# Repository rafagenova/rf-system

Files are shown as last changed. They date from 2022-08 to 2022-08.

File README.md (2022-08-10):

# radio frequency system for sending and reception of data

## 1. NRF905 notes

### &bull; nrf905 timing to obey info

| nrf905 timing | max | 
| --- | --- |
| power down mode to standby mode | 3 ms |
| standby mode to TX shock burst mode | 650 us |
| standby mode to RX shock burst mode | 650 us |
| RX shock burst mode to TX shock burst mode | 550 us |
| TX shock burst mode to RX shock burst mode | 550 us |

### &bull; nrf905 modulation
the modulation of nRF905 is Gaussian Frequency Shift Keying (GFSK) with a datarate of 100kbps.
</br> the data is internally Manchester encoded (TX) and Manchester decoded (RX).

### &bull; nrf905 output frequency

Output Frequency
The operating RF-frequency of nRF905 is set in the configuration register by CH_NO and HFREQ_PLL.

| operating frequency|
| ----------- | 
| <i> f = (422.4 + (CH_NO)/10)&bull; (1 + HFREQ_PLL) MHz </i>| 

<i> obs1: CH_NO varies from '000000000' to '1111111111' </i>

<i> obs2: HFREQ_PLL varies from '0' to '1' </i>

| Operating frequency | HFREQ_PLL | CH_NO | 
| --- | --- | --- |
| 430.0 MHz |  [0] | [001001100]  |
| 433.1 MHz |  [0] | [001101011]  |
| 433.2 MHz |  [0] | [001101100]  |
| 434.7 MHz |  [0] | [001111011]  |
| 862.0 MHz |  [1] | [001010110]  |
| 868.2 MHz |  [1] | [001110101]  |
| 868.4 MHz |  [1] | [001110110]  |
| 869.8 MHz |  [1] | [001111101]  |
| 902.2 MHz |  [1] | [100011111]  |
| 902.4 MHz |  [1] | [100100000]  |
| 927.8 MHz |  [1] | [110011111]  |

### &bull; nrf905 antenna ports impedance

| optimum differential load impedance at the antenna ports| frequency | 
| --- | --- |
| 225&Omega; + j210 |  900MHz | 
| 300&Omega; + j100 |  430MHz | 

<i> obs: a low load impedance (for instance 50&Omega;) can be obtained by fitting a simple matching network or a RF transformer (balun) </i>

### &bull; PCB layout and decoupling guidelines

<i> 

1. A PCB with a minimum of two layers including a ground plane is recommended for optimum performance.

2. The nRF905 DC supply voltage should be decoupled as close as possible to the VDD pins with high performance RF capacitors.

3. It is preferable to mount a large surface mount capacitor (e.g. 4.7uF tantalum) in parallel with the smaller value capacitors.

4. The nRF905 supply voltage should be filtered and routed separately from the supply voltages of any digital circuitry.

5. Long power supply lines on the PCB should be avoided.

6. All device grounds, VDD connections and VDD bypass capacitors must be connected as close as possible to the nRF905 IC.

7. For a PCB with a topside RF ground plane, the VSS pins should be connected directly to the ground plane.

8. For a PCB with a bottom ground plane, the best technique is to place via holes as close as possible to the VSS pins (a minimum of one via hole should be used for each VSS pin).

9. Full swing digital data or control signals should not be routed close to the crystal or the power supply lines.

10. A fully qualified RF-layout for the nRF905 and its surrounding components, including antennas and matching networks, can be downloaded from <b> www.nordicsemi.no. </b>

</i>

| nrf905 features | description | 
| --- | --- |
| &bull; Carrier detect | When the nRF905 is in ShockBurst TM RX, the Carrier Detect (CD) pin is set high if a RF carrier is present at the channel the device is programmed to. </br > </br > This feature is very effective to avoid collision of packages from different transmitters operating at the same frequency. </br > </br > Whenever a device is ready to transmit it could first be set into receive mode and sense whether or not the wanted channel is available for outgoing data. |
| &bull; Address match | When the nRF905 is in ShockBurst TM RX mode, the Address Match (AM) pin is set high as soon as an incoming package with an address that is identical with the device’s own identity is received. </br > </br > If Address Match (AM) is high then the MCU can make a decision to wait and see if Data Ready (DR) will be set high indicating a valid data package has been received or ignore that a possible package is being received and switch modes.|
|  &bull; Data ready | In ShockBurst TM TX Auto Retransmit the Data Ready (DR) signal is set high at the beginning of the pre-amble and is set low at the end of the preamble. The Data Ready (DR) signal therefore pulses at the beginning of each transmitted data packet.  </br > </br > In ShockBurst TM RX, the signal is set high when nRF905 has received a valid package, i.e. a valid address, package length and correct CRC. The MCU can then retrieve the payload via the SPI interface. The Data Ready (DR) pin is reset to low once the data has been clocked out of the data buffer or the device is switched to transmit mode.|
|  &bull; Auto retransmit | One way to increase system reliability in a noisy environment or in a system without collision control is to transmit a package several times. </br > </br > By setting the AUTO_RETRAN bit to “1” in the configuration register, the circuit keeps sending the same data package as long as TRX_CE and TX_EN is high.|

### &bull; nrf905 schematic example

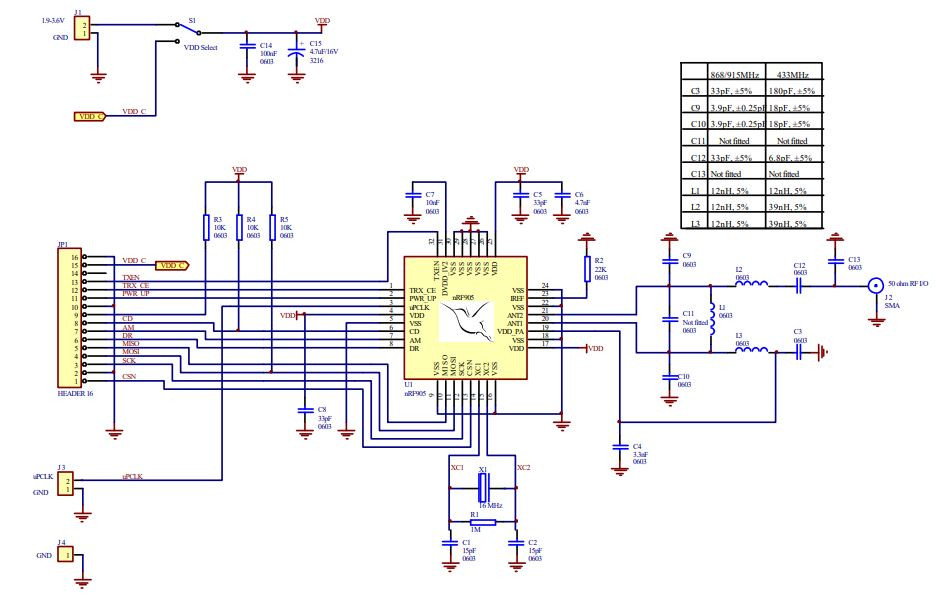
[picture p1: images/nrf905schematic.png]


## 2. Components & schematics

### &bull; voltage regulator (3.7v battery to 3.3v system)

| 3.3V LDO | packacge | comments |
| --- | --- |  --- |
| MCP1700T-3302E/TT |  SOT-23-3 |46 in stock at JLCPCB @ 30/05 <br /> Max current of 250 mA <br /> Max dropout voltage of 350 mV |

### &bull; power input schematic

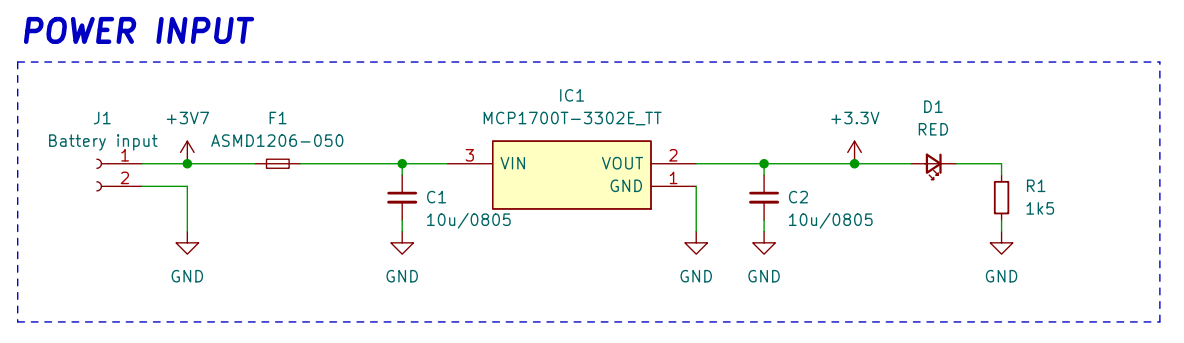
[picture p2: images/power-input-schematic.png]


### &bull; transceiver schematic

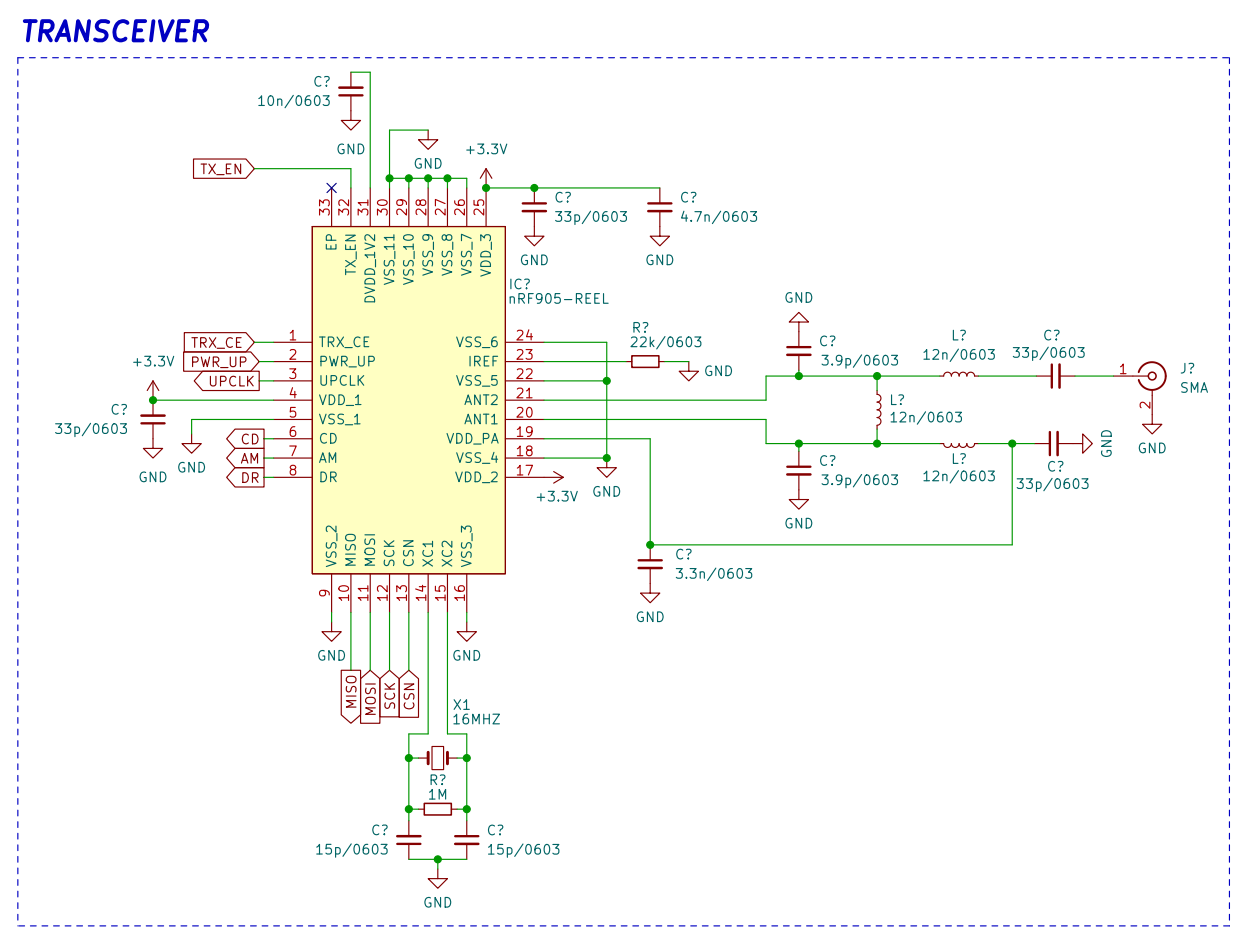
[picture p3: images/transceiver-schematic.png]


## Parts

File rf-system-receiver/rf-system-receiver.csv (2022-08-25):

Comment | Designator | Footprint | LCSC Part #
33p/0603 Unpolarized capacitor, small symbol | C1,C6,C12,C13 | C_0603_1608Metric
22u/1206 Unpolarized capacitor, small symbol | C2,C8 | C_1206_3216Metric
10n/0603 Unpolarized capacitor, small symbol | C3 | C_0603_1608Metric
10p/0402 Unpolarized capacitor, small symbol | C4,C5,C19,C20 | C_0402_1005Metric
3.3n/0603 Unpolarized capacitor, small symbol | C7 | C_0603_1608Metric
4.7n/0603 Unpolarized capacitor, small symbol | C9 | C_0603_1608Metric
3.9p/0603 Unpolarized capacitor, small symbol | C10,C11 | C_0603_1608Metric
10u/0805 Unpolarized capacitor, small symbol | C14,C21 | C_0805_2012Metric
100n/0402 Unpolarized capacitor, small symbol | C15,C16,C17,C18,C23 | C_0402_1005Metric
10n/0402 Unpolarized capacitor, small symbol | C22 | C_0402_1005Metric
RED Light emitting diode, small symbol | D1,D2 | LED_0603_1608Metric
ASMD1206-050 Fuse, small symbol | F1 | Fuse_1206_3216Metric
100@100MHz/0603 Ferrite bead, small symbol | FB1 | L_0603_1608Metric
Fiducial Fiducial Marker | FID1,FID2,FID3,FID4 | Fiducial_1mm_Mask2mm
MountingHole Mounting Hole without connection | H1,H3 | MountingHole_3.2mm_M3
nRF905 HF-Transceiver 1.9-3.6V 433/868/ 915MHz TRNSCVR | IC1 | nrf905
USB_B_Micro USB Connectors 5P MICRO USB TYPE B RECEPTACLE W/ PEGS | J1 | 101181930001LF
CONREVSMA001-G RF Connectors / Coaxial Connectors RP-SMA Female PCB Mount - Gold | J2 | CONREVSMA001G
SWD Generic connector, double row, 02x05, odd/even pin numbering scheme (row 1 odd numbers, row 2 even numbers), script generated (kicad-library-utils/schlib/autogen/connector/) | J3 | PinHeader_2x05_P2.54mm_Vertical_SMD
12n/0603 Inductor, small symbol | L1,L2,L3 | L_0603_1608Metric
MMBT9013 NPN transistor, base/collector/emitter | Q1 | SOT-23
1M/0402 Resistor, small symbol | R1 | R_0402_1005Metric
22k/0603 Resistor, small symbol | R2 | R_0603_1608Metric
1k5/0603 Resistor, small symbol | R3,R7 | R_0603_1608Metric
10k/0603 Resistor, small symbol | R4,R6,R9 | R_0603_1608Metric
47R/0402 Resistor, small symbol | R5 | R_0402_1005Metric
100R/0603 Resistor, small symbol | R8,R11 | R_0603_1608Metric
36k/0603 Resistor, small symbol | R10 | R_0603_1608Metric
SW_Push Push button switch, generic, two pins | SW1 | SW_PUSH_6mm
STM32F103C8Tx ARM Cortex-M3 MCU, 64KB flash, 20KB RAM, 72MHz, 2-3.6V, 37 GPIO, LQFP-48 | U1 | LQFP-48_7x7mm_P0.5mm
AMS1117-3.3 1A Low Dropout regulator, positive, 3.3V fixed output, SOT-223 | U2 | SOT-223-3_TabPin2
16MHZ Four pin crystal, GND on pins 2 and 4, small symbol | X1,X2 | Crystal_SMD_3225-4Pin_3.2x2.5mm

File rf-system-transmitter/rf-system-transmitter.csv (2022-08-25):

Comment | Designator | Footprint | LCSC Part #
33p/0603 Unpolarized capacitor, small symbol | C1,C6,C13 | C_0603_1608Metric
10u/0805 Unpolarized capacitor, small symbol | C2,C8,C14,C21 | C_0805_2012Metric
10n/0603 Unpolarized capacitor, small symbol | C3 | C_0603_1608Metric
10p/0402 Unpolarized capacitor, small symbol | C4,C5,C19,C20 | C_0402_1005Metric
3.3n/0603 Unpolarized capacitor, small symbol | C7 | C_0603_1608Metric
4.7n/0603 Unpolarized capacitor, small symbol | C9 | C_0603_1608Metric
3.9p/0603 Unpolarized capacitor, small symbol | C10,C11 | C_0603_1608Metric
2.2p/0603 Unpolarized capacitor, small symbol | C12 | C_0603_1608Metric
100n/0402 Unpolarized capacitor, small symbol | C15,C16,C17,C18,C23 | C_0402_1005Metric
10n/0402 Unpolarized capacitor, small symbol | C22 | C_0402_1005Metric
RED Light emitting diode, small symbol | D1,D2 | LED_0603_1608Metric
ASMD1206-050 Fuse, small symbol | F1 | Fuse_1206_3216Metric
100@100MHz/0603 Ferrite bead, small symbol | FB1 | L_0603_1608Metric
Fiducial Fiducial Marker | FID1,FID2,FID3,FID4 | Fiducial_1mm_Mask2mm
MountingHole Mounting Hole without connection | H1,H4 | MountingHole_3.2mm_M3
nRF905 HF-Transceiver 1.9-3.6V 433/868/ 915MHz TRNSCVR | IC1 | nrf905
MCP1700T-3302E_TT LDO voltage regulator 250mA Isupply 1uA | IC2 | MCP1700T-3302E_TT
Battery input Generic connector, single row, 01x02, script generated (kicad-library-utils/schlib/autogen/connector/) | J1 | JST_PH_B2B-PH-K_1x02_P2.00mm_Vertical
CONREVSMA001-G RF Connectors / Coaxial Connectors RP-SMA Female PCB Mount - Gold | J2 | CONREVSMA001G
SWD Generic connector, double row, 02x05, odd/even pin numbering scheme (row 1 odd numbers, row 2 even numbers), script generated (kicad-library-utils/schlib/autogen/connector/) | J3 | PinHeader_2x05_P2.54mm_Vertical_SMD
12n/0603 Inductor, small symbol | L1,L2,L3 | L_0603_1608Metric
1M/0402 Resistor, small symbol | R1 | R_0402_1005Metric
22k/0603 Resistor, small symbol | R2 | R_0603_1608Metric
1k5/0603 Resistor, small symbol | R3,R7 | R_0603_1608Metric
10k/0603 Resistor, small symbol | R4,R6 | R_0603_1608Metric
47R/0402 Resistor, small symbol | R5 | R_0402_1005Metric
SW_Push Push button switch, generic, two pins | SW1 | SW_PUSH_6mm
STM32F103C8Tx ARM Cortex-M3 MCU, 64KB flash, 20KB RAM, 72MHz, 2-3.6V, 37 GPIO, LQFP-48 | U1 | LQFP-48_7x7mm_P0.5mm
16MHZ Four pin crystal, GND on pins 2 and 4, small symbol | X1,X2 | Crystal_SMD_3225-4Pin_3.2x2.5mm

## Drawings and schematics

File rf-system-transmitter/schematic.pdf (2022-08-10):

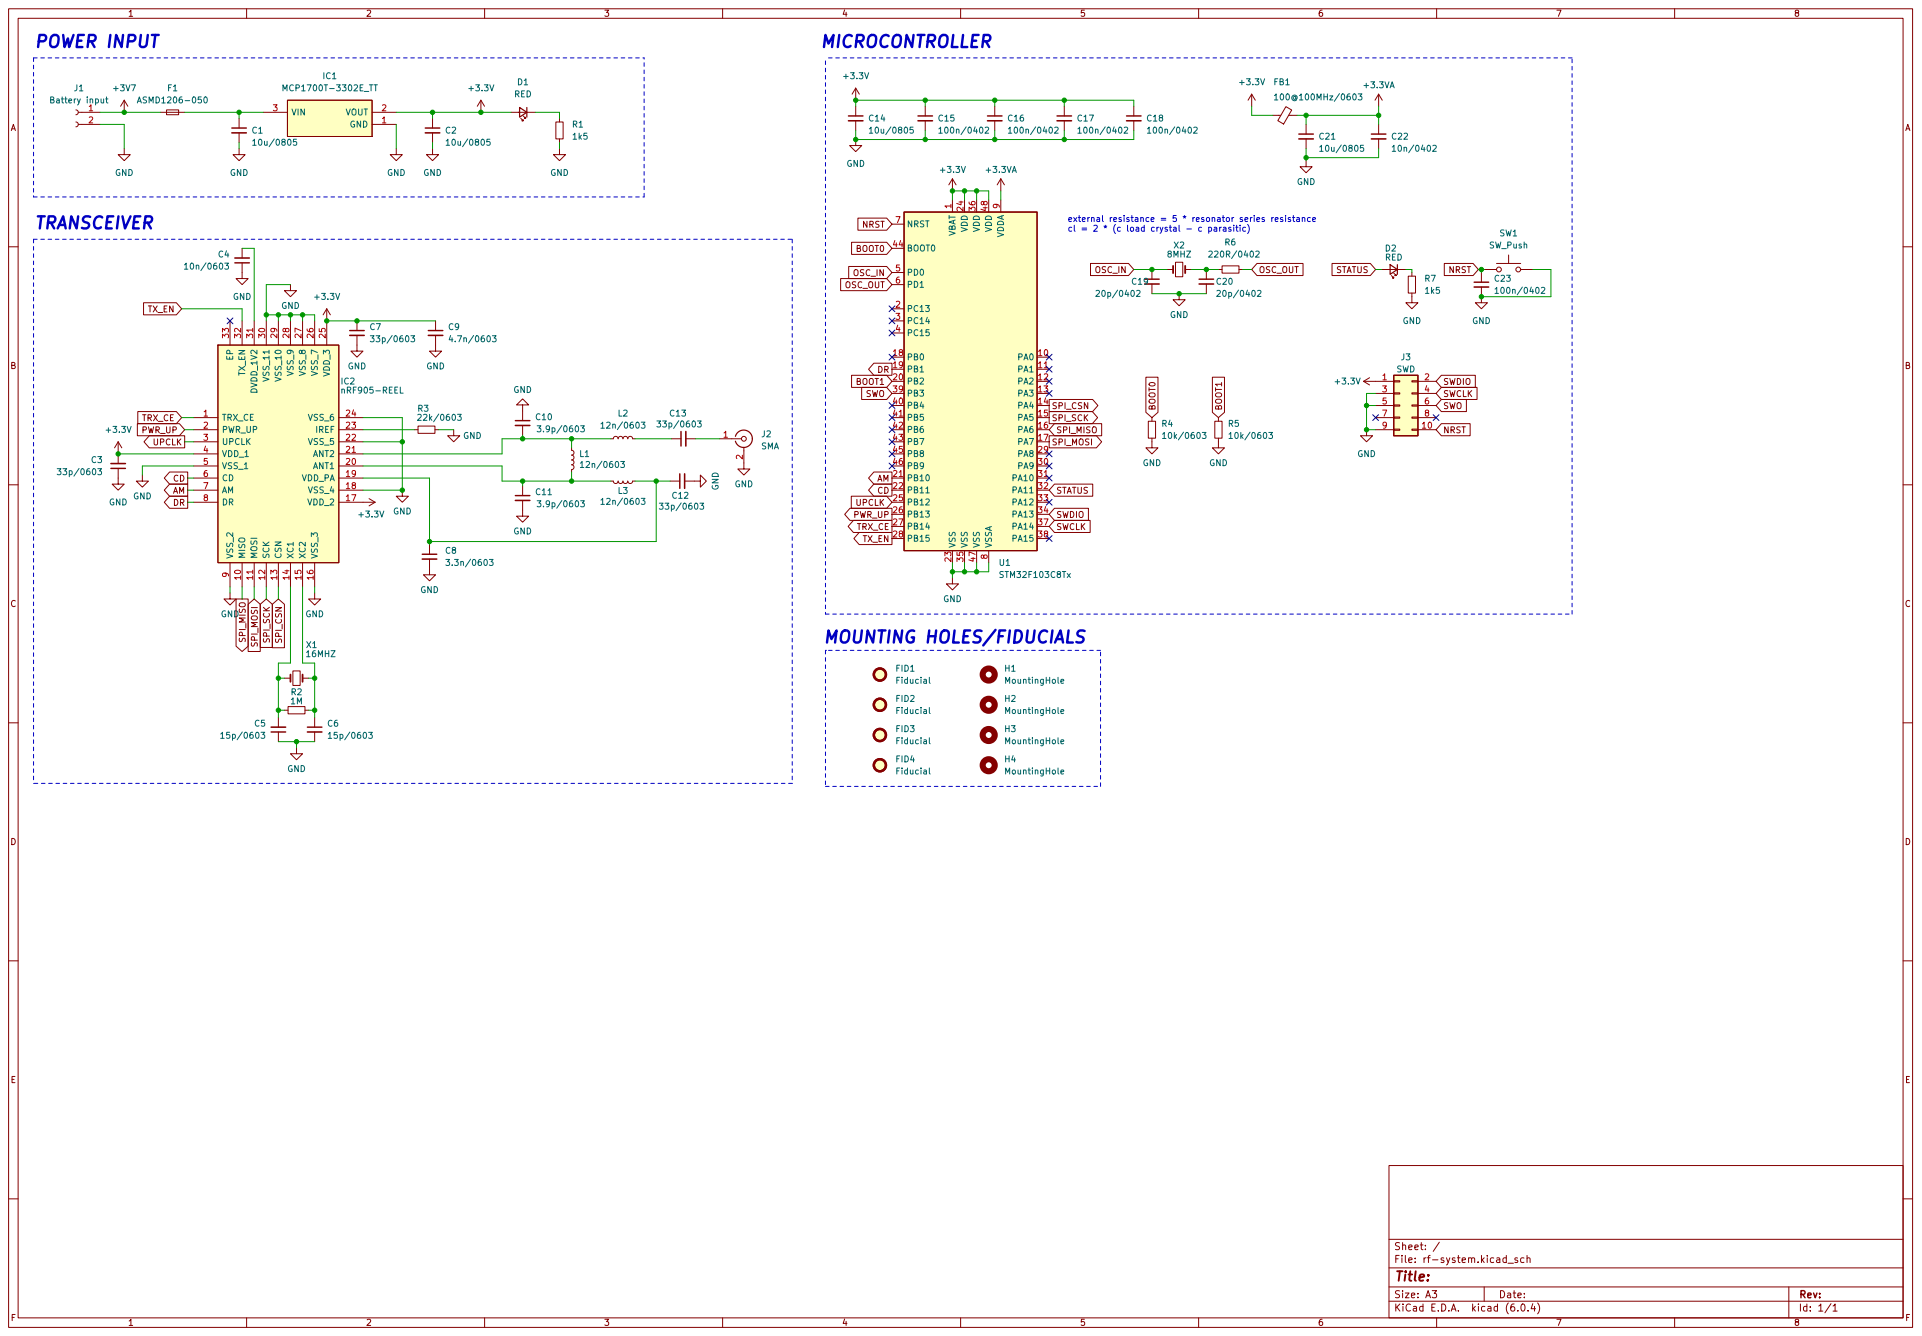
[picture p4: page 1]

1 PA0 10 PA1 11 PA2 12 PA3 13 PA4 14 PA5 15 PA6 16 PA7 17 PB0 18 PB1 19 PC13 2 PB2 20 PB10 21 PB11 22 VSS 23 VDD 24 PB12 25 PB13 26 PB14 27 PB15 28 PA8 29 PC14 3 PA9 30 PA10 31 PA11 32 PA12 33 PA13 34 VSS 35 VDD 36 PA14 37 PA15 38 PB3 39 PC15 4 PB4 40 PB5 41 PB6 42 PB7 43 BOOT0 44 PB8 45 PB9 46 VSS 47 VDD 48 PD0 5 PD1 6 NRST 7 VSSA

cl = 2 * (c load crystal - c parasitic)

SWCLK NRST MOUNTING HOLES/FIDUCIALS
SPI_CSN OSC_OUT SWO

File: rf-system.kicad_sch Sheet: /

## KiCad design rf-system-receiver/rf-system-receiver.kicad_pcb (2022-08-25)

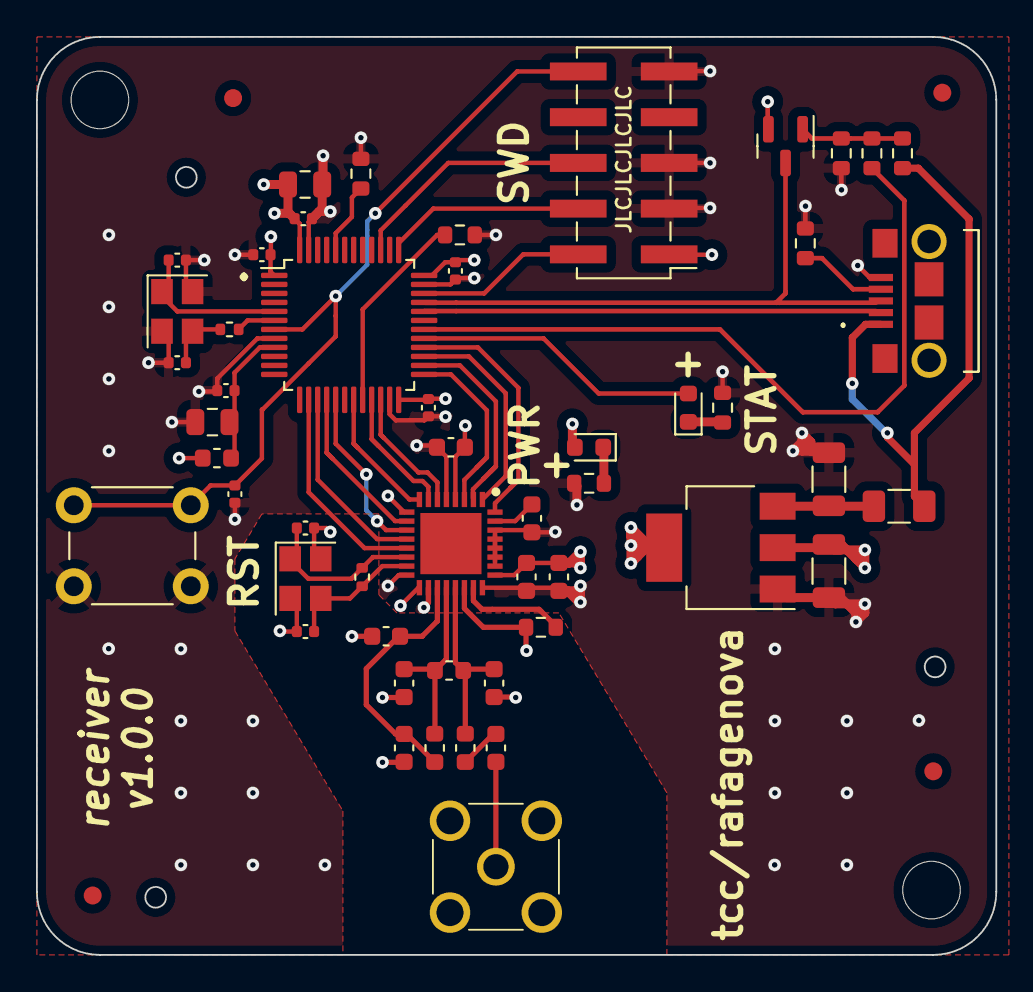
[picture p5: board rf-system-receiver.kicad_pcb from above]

Board: 4 copper layers, 53.3 x 51.0 mm, 57 parts (0 on the bottom side), 42 nets.

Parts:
C1, C6, C12, C13: 33p/0603; C_0603_1608Metric
C2, C8: 22u/1206; C_1206_3216Metric
C3: 10n/0603; C_0603_1608Metric
C4, C5, C19, C20: 10p/0402; C_0402_1005Metric
C7: 3.3n/0603; C_0603_1608Metric
C9: 4.7n/0603; C_0603_1608Metric
C10, C11: 3.9p/0603; C_0603_1608Metric
C14, C21: 10u/0805; C_0805_2012Metric
C15, C16, C17, C18, C23: 100n/0402; C_0402_1005Metric
C22: 10n/0402; C_0402_1005Metric
D1, D2: RED; LED_0603_1608Metric
F1: ASMD1206-050; Fuse_1206_3216Metric
FB1: 100@100MHz/0603; L_0603_1608Metric
FID1, FID2, FID3, FID4: Fiducial; Fiducial_1mm_Mask2mm
H1, H3: MountingHole; MountingHole_3.2mm_M3
IC1: nRF905; nrf905
J1: USB_B_Micro; 101181930001LF
J2: CONREVSMA001-G; CONREVSMA001G
J3: SWD; PinHeader_2x05_P2.54mm_Vertical_SMD
L1, L2, L3: 12n/0603; L_0603_1608Metric
Q1: MMBT9013; SOT-23
R1: 1M/0402; R_0402_1005Metric
R2: 22k/0603; R_0603_1608Metric
R3, R7: 1k5/0603; R_0603_1608Metric
R4, R6, R9: 10k/0603; R_0603_1608Metric
R5: 47R/0402; R_0402_1005Metric
R8, R11: 100R/0603; R_0603_1608Metric
R10: 36k/0603; R_0603_1608Metric
SW1: SW_Push; SW_PUSH_6mm
U1: STM32F103C8Tx; LQFP-48_7x7mm_P0.5mm
U2: AMS1117-3.3; SOT-223-3_TabPin2
X1, X2: 16MHZ; Crystal_SMD_3225-4Pin_3.2x2.5mm

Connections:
+3.3VA: C21.1, C22.1, FB1.2, U1.9 (VDDA)
+3V3: C1.2, C6.1, C8.1, C9.1, C14.1, C15.1, C16.1, C17.1, C18.1, D1.2 (A), FB1.1, IC1.4 (VDD_1), IC1.17 (VDD_2), IC1.25 (VDD_3), J3.1, Q1.2 (C), U1.1 (VBAT), U1.24 (VDD), U1.36 (VDD), U1.48 (VDD), U2.2 (VO)
+5V: F1.1, J1.1 (VBUS), R9.1
AM: IC1.7 (AM), U1.21 (PB10)
BOOT0: R4.1, U1.44 (BOOT0)
BOOT1: R6.1, U1.20 (PB2)
CD: IC1.6 (CD), U1.22 (PB11)
DR: IC1.8 (DR), U1.19 (PB1)
GND: C1.1, C2.2, C3.1, C4.2, C5.2, C6.2, C7.2, C8.2, C9.2, C10.1, C11.2, C12.2, C14.2, C15.2, C16.2, C17.2, C18.2, C19.2, C20.2, C21.2, C22.2, C23.2, IC1.5 (VSS_1), IC1.9 (VSS_2), IC1.16 (VSS_3), IC1.18 (VSS_4), IC1.22 (VSS_5), IC1.24 (VSS_6), IC1.26 (VSS_7), IC1.27 (VSS_8), IC1.28 (VSS_9), IC1.29 (VSS_10), IC1.30 (VSS_11), J1.5 (GND), J2.2, J2.3, J2.4, J2.5, J3.3, J3.5, J3.9, R2.2, R3.2, R4.2, R6.2, R7.2, R8.2, R10.2, SW1.2, U1.8 (VSSA), U1.23 (VSS), U1.35 (VSS), U1.47 (VSS), U2.1 (GND), X1.2, X1.4, X2.2, X2.4
NRST: C23.1, J3.10, SW1.1, U1.7 (NRST)
unnamed: C2.1, F1.2, U2.3 (VI)
unnamed: C3.2, IC1.31 (DVDD_1V2)
unnamed: C10.2, IC1.21 (ANT2), L1.1, L2.1
unnamed: C11.1, IC1.20 (ANT1), L1.2, L3.2
unnamed: C7.1, C12.1, IC1.19 (VDD_PA), L3.1
unnamed: C13.1, L2.2
unnamed: C13.2, J2.1
unnamed: C20.1, R5.1, X2.3
unnamed: D1.1 (K), R3.1
unnamed: D2.1 (K), R7.1
unnamed: IC1.23 (IREF), R2.1
unnamed: J1.4 (ID), R8.1
unnamed: Q1.1 (B), R9.2, R10.1, R11.1
OSC_IN: C19.1, U1.5 (PD0), X2.1
OSC_OUT: R5.2, U1.6 (PD1)
PWR_UP: IC1.2 (PWR_UP), U1.26 (PB13)
SPI_CSN: IC1.13 (CSN), U1.14 (PA4)
SPI_MISO: IC1.10 (MISO), U1.16 (PA6)
SPI_MOSI: IC1.11 (MOSI), U1.17 (PA7)
SPI_SCK: IC1.12 (SCK), U1.15 (PA5)
STATUS: D2.2 (A), U1.29 (PA8)
SWCLK: J3.4, U1.37 (PA14)
SWDIO: J3.2, U1.34 (PA13)
SWO: J3.6, U1.39 (PB3)
TRX_CE: IC1.1 (TRX_CE), U1.27 (PB14)
TX_EN: IC1.32 (TX_EN), U1.28 (PB15)
UPCLK: IC1.3 (UPCLK), U1.25 (PB12)
USB_D+: J1.3 (D+), Q1.3 (E), U1.33 (PA12)
USB_D-: J1.2 (D-), U1.32 (PA11)
USB_PULLUP: R11.2, U1.30 (PA9)
XC1: C4.1, IC1.14 (XC1), R1.2, X1.1
XC2: C5.1, IC1.15 (XC2), R1.1, X1.3

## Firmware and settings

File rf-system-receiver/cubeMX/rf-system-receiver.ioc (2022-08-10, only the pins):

Mcu.UserName=STM32F103C8Tx
PA11.Signal=USB_DM
PA12.Signal=USB_DP
PA13.Signal=SYS_JTMS-SWDIO
PA14.Signal=SYS_JTCK-SWCLK
PA4.GPIO_Label=SPI1_CSN
PA4.Signal=GPIO_Output
PA5.Signal=SPI1_SCK
PA6.Signal=SPI1_MISO
PA7.Signal=SPI1_MOSI
PB1.GPIO_Label=DR
PB1.Signal=GPIO_Output
PB10.GPIO_Label=AM
PB10.Signal=GPIO_Output
PB11.GPIO_Label=CD
PB11.Signal=GPIO_Output
PB12.GPIO_Label=UP_CLK
PB12.Signal=GPIO_Output
PB13.GPIO_Label=PWR_UP
PB13.Signal=GPIO_Output
PB14.GPIO_Label=TRX_CE
PB14.Signal=GPIO_Output
PB15.GPIO_Label=TX_EN
PB15.Signal=GPIO_Output
PB3.Signal=SYS_JTDO-TRACESWO
PD0-OSC_IN.Signal=RCC_OSC_IN
PD1-OSC_OUT.Signal=RCC_OSC_OUT

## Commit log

2022-08-10 add projects
    [Loop_35x20mm_433MHz_nRF9x5.DRL, Loop_35x20mm_433MHz_nRF9x5.GBS, Loop_35x20mm_433MHz_nRF9x5.GTL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]
2022-08-10 add full projects
    [rf-system-receiver.kicad_pcb, rf-system-receiver.kicad_sch]
2022-08-10 add projects to rf-system file
    [Loop_35x20mm_433MHz_nRF9x5.DRL, Loop_35x20mm_433MHz_nRF9x5.GBS, Loop_35x20mm_433MHz_nRF9x5.GTL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]
2022-08-10 ibom added
    [Loop_35x20mm_433MHz_nRF9x5.DRL, Loop_35x20mm_433MHz_nRF9x5.GBS, Loop_35x20mm_433MHz_nRF9x5.GTL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]
2022-08-11 add silkscreen, fiducials and tooling holes
    [rf-system-receiver.kicad_pcb, rf-system-receiver.kicad_sch, rf-system-transmitter.kicad_pcb]
2022-08-25 adding LCSC Part # and small PCB modifs
    [receiver-positions.csv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]
